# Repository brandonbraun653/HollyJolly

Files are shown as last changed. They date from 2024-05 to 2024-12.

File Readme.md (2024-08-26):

# First Clone
Initialize the Pico-SDK by running the following commands:
```bash
git submodule init
cd lib/pico-sdk
git submodule init
```

# Install the OpenOCD Debugger
The latest version of OpenOCD includes support for the RPI pico. Follow the
instructions here to compile and install from source:
https://github.com/openocd-org/openocd

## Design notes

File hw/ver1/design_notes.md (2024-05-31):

- From initial testing, the WS2812 needs to have the data line level shifted up to 5v. I got lucky in that my
chips in my neopixel string accepted the 3.3v logic level of the RP2040.

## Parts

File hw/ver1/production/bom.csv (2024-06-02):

Designator | Footprint | Quantity | Value | LCSC Part #
C1, C13, C14, C17, C18, C19, C20, C21, C22, C23, C24, C25, C26, C27, C28, C29, C3, C30, C31, C32, C33, C34, C35, C36, C37, C38, C39, C4, C40, C41, C42, C43, C44, C45, C46, C47, C48, C49, C5, C50, C6, C7, C8, C9 | 0402 | 44 | 100nF | C1525
C10, C11, C12, C2 | 0402 | 4 | 4.7uF | C23733
C15, C16 | 0402 | 2 | 10pF | C32949
D1, D10, D11, D12, D13, D14, D15, D16, D17, D18, D19, D2, D20, D21, D22, D23, D24, D25, D26, D27, D28, D29, D3, D30, D31, D32, D4, D5, D6, D7, D8, D9 | LED_WS2812B-2020_PLCC4_2.0x2.0mm | 32 | WS2812B-2020 | C5349955
J1 | MicroXNJ073 | 1 | USB_B_Micro | C404969
Q1 | SOT-23 | 1 | 2N7002 | C8545
R1, R2, R5, R6, R7, R8 | 0402 | 6 | 10k | C25744
R3, R4 | 0402 | 2 | 22 | C25092
SW1 | SW_Push_SPST_NO_Alps_SKRK | 1 | BOOT | C262416
SW2 | SW_Push_SPST_NO_Alps_SKRK | 1 | CYCLE | C262416
SW3 | SW_Push_SPST_NO_Alps_SKRK | 1 | BRIGHT | C262416
TP1 | TestPoint_Pad_1.0x1.0mm | 1 | SWD_CLK
TP2 | TestPoint_Pad_1.0x1.0mm | 1 | SWD_DATA
TP3 | TestPoint_Pad_1.0x1.0mm | 1 | LED_DATA_TP
U1 | QFN-56-1EP_7x7mm_P0.4mm_EP3.2x3.2mm | 1 | RP2040 | C2040
U2 | SOIC-8_5.23x5.23mm_P1.27mm | 1 | W25Q128JVS | C97521
U3 | SOT-23-3 | 1 | XC6206PxxxMR | C5446
Y1 | Crystal_SMD_3225-4Pin_3.2x2.5mm | 1 | 12MHz | C9002

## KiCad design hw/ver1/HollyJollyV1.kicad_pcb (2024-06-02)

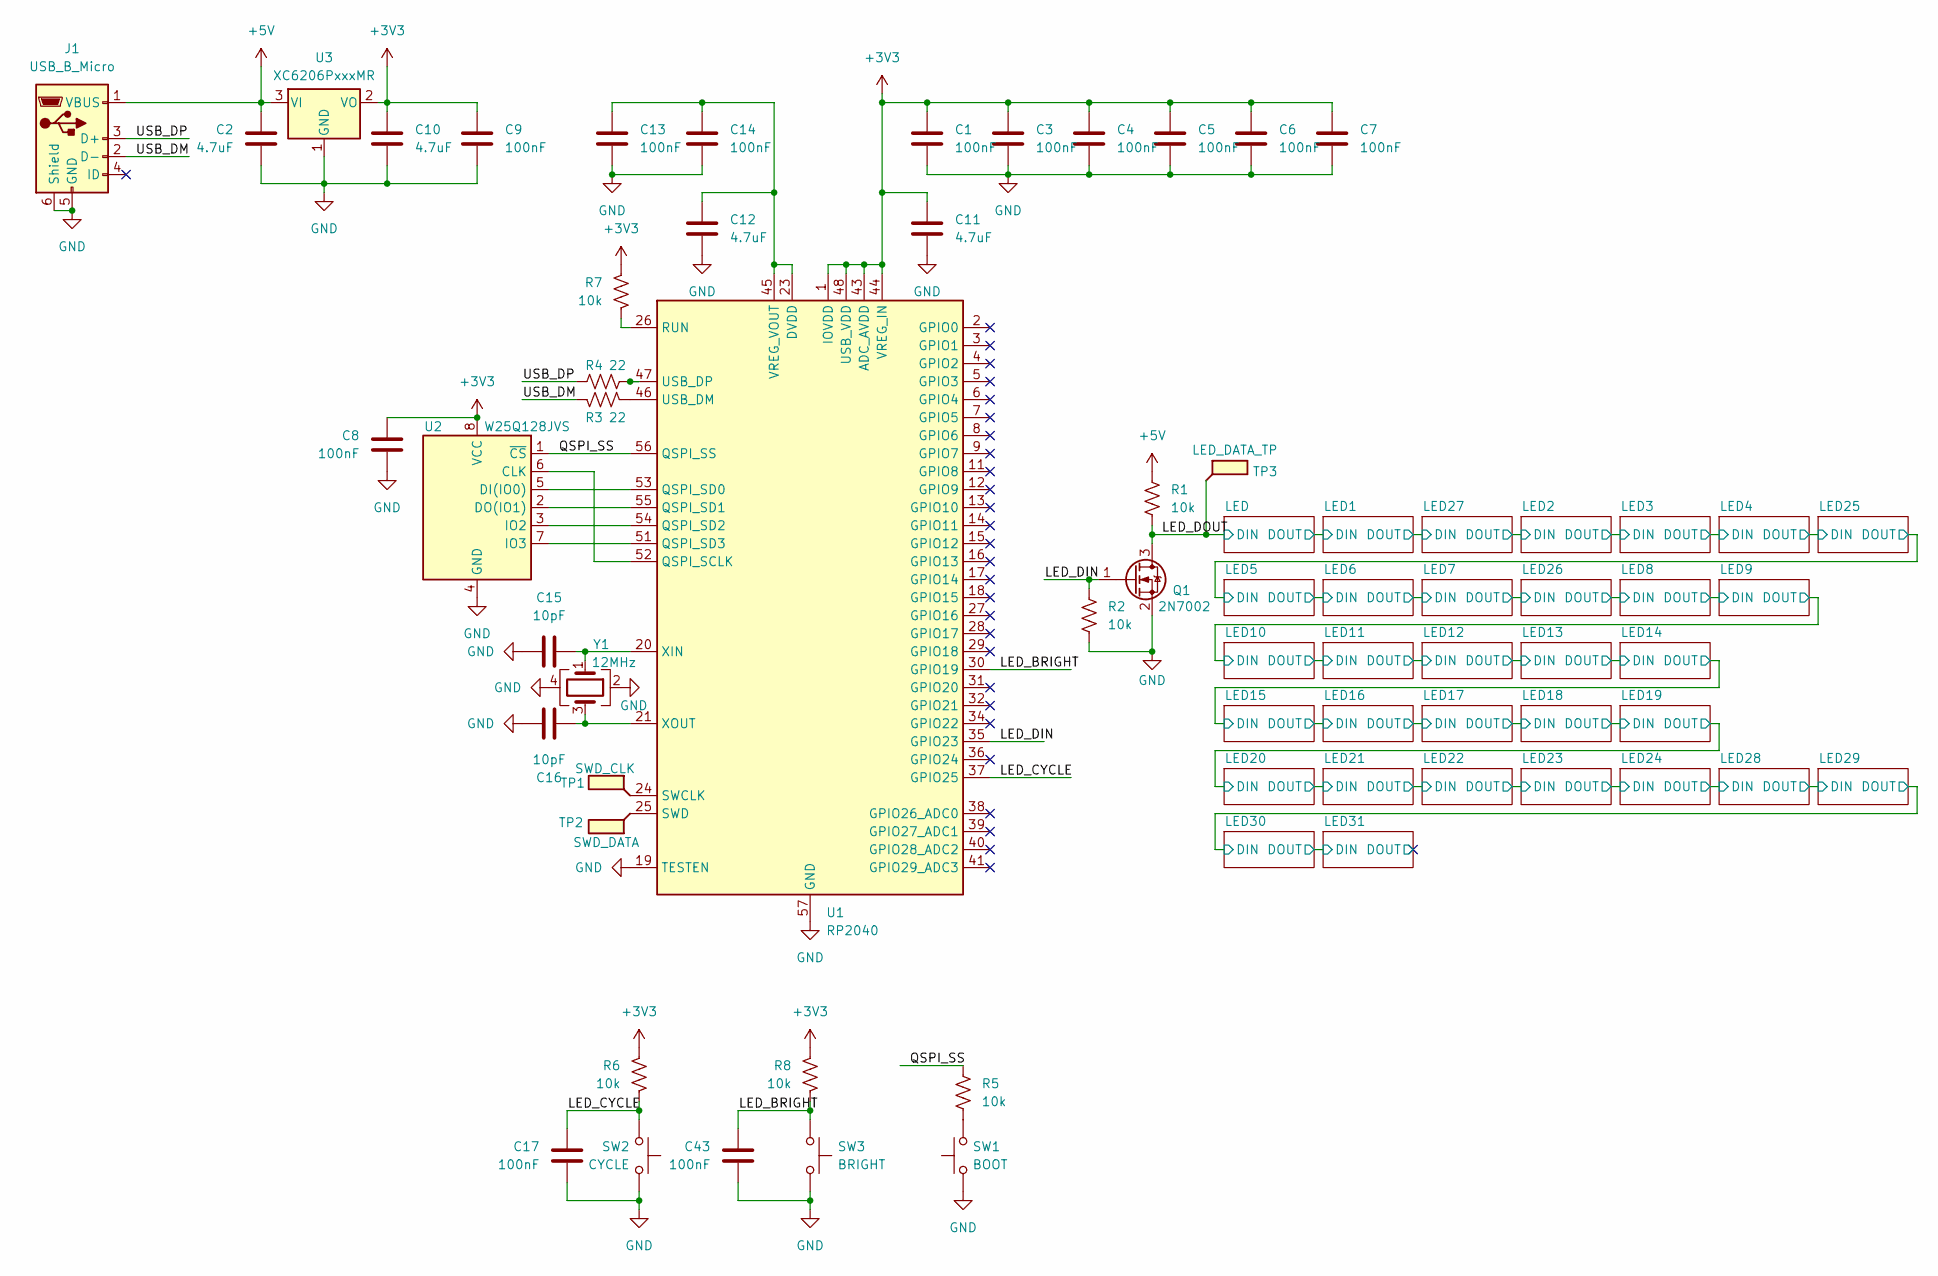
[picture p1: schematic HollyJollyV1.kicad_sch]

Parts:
C1, C3, C4, C5, C6, C7, C8, C9, C13, C14, C17, C43: 100nF; C_0402_1005Metric; MPN CL05B104KO5NNNC; LCSC C1525
C2, C10, C11, C12: 4.7uF; C_0402_1005Metric; MPN CL05A475MP5NRNC; LCSC C23733
C15, C16: 10pF; C_0402_1005Metric; MPN CL05C100JB5NNNC; LCSC C32949
J1: USB_B_Micro; MicroXNJ073; MPN MicroXNJ073; LCSC C404969
Q1: 2N7002; SOT-23; MPN 2N7002; LCSC C8545
R1, R2, R5, R6, R7, R8: 10k; R_0402_1005Metric; MPN 0402WGF1002TCE; LCSC C25744
R3, R4: 22; R_0402_1005Metric; MPN 0402WGF220JTCE; LCSC C25092
SW1: BOOT; SW_Push_SPST_NO_Alps_SKRK; MPN SKRKAGE020; LCSC C262416
SW2: CYCLE; SW_Push_SPST_NO_Alps_SKRK; MPN SKRKAGE020; LCSC C262416
SW3: BRIGHT; SW_Push_SPST_NO_Alps_SKRK; MPN SKRKAGE020; LCSC C262416
TP1: SWD_CLK; TestPoint_Pad_1.0x1.0mm
TP2: SWD_DATA; TestPoint_Pad_1.0x1.0mm
TP3: LED_DATA_TP; TestPoint_Pad_1.0x1.0mm
U1: RP2040; QFN-56-1EP_7x7mm_P0.4mm_EP3.2x3.2mm; MPN RP2040; LCSC C2040
U2: W25Q128JVS; SOIC-8_5.23x5.23mm_P1.27mm; MPN W25Q128JVSIQ; LCSC C97521
U3: XC6206PxxxMR; SOT-23-3; MPN XC6206P332MR-G; LCSC C5446
Y1: 12MHz; Crystal_SMD_3225-4Pin_3.2x2.5mm; MPN X322512MSB4SI; LCSC C9002

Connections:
+3V3: C1.1, C3.1, C4.1, C5.1, C6.1, C7.1, C8.1, C9.1, C10.1, C11.1, R6.2, R7.1, R8.2, U1.1 (IOVDD), U1.10 (IOVDD), U1.22 (IOVDD), U1.33 (IOVDD), U1.42 (IOVDD), U1.43 (ADC_AVDD), U1.44 (VREG_IN), U1.48 (USB_VDD), U1.49 (IOVDD), U2.8 (VCC), U3.2 (VO)
+5V: C2.1, J1.1 (VBUS), R1.1, U3.3 (VI); also elsewhere on the board
/LED_BRIGHT: C43.1, R8.1, SW3.2, U1.30 (GPIO19)
/LED_CYCLE: C17.1, R6.1, SW2.2, U1.37 (GPIO25)
/LED_DIN: Q1.1 (G), R2.1, U1.35 (GPIO23)
/LED_DOUT: Q1.3 (D), R1.2, TP3.1; also elsewhere on the board
/QSPI_SS: R5.1, U1.56 (QSPI_SS), U2.1 (~CS)
/USB_DM: J1.2 (D-), R3.1
/USB_DP: J1.3 (D+), R4.1
GND: C1.2, C2.2, C3.2, C4.2, C5.2, C6.2, C7.2, C8.2, C9.2, C10.2, C11.2, C12.2, C13.2, C14.2, C15.1, C16.1, C17.2, C43.2, J1.5 (GND), J1.6 (Shield), Q1.2 (S), R2.2, SW1.1, SW2.1, SW3.1, U1.19 (TESTEN), U1.57 (GND), U2.4 (GND), U3.1 (GND), Y1.2, Y1.4; also elsewhere on the board
unnamed: R5.2, SW1.2
unnamed: U1.52 (QSPI_SCLK), U2.6 (CLK)
unnamed: U1.53 (QSPI_SD0), U2.5 (DI(IO0))
unnamed: U1.55 (QSPI_SD1), U2.2 (DO(IO1))
unnamed: U1.54 (QSPI_SD2), U2.3 (IO2)
unnamed: U1.51 (QSPI_SD3), U2.7 (IO3)
unnamed: R7.2, U1.26 (RUN)
unnamed: TP1.1, U1.24 (SWCLK)
unnamed: TP2.1, U1.25 (SWD)
unnamed: R3.2, U1.46 (USB_DM)
unnamed: R4.2, U1.47 (USB_DP)
unnamed: C12.1, C13.1, C14.1, U1.23 (DVDD), U1.45 (VREG_VOUT), U1.50 (DVDD)
unnamed: C15.2, U1.20 (XIN), Y1.1
unnamed: C16.2, U1.21 (XOUT), Y1.3

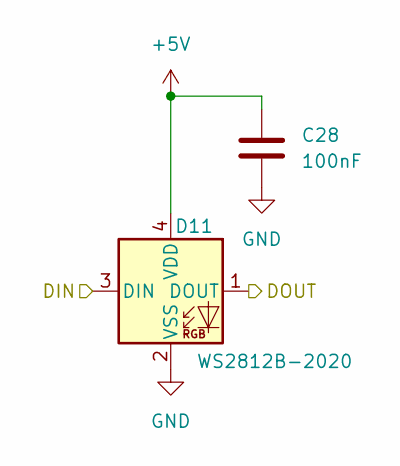
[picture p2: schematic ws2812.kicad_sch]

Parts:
C28: 100nF; C_0402_1005Metric; MPN CL05B104KO5NNNC; LCSC C1525
D11: WS2812B-2020; LED_WS2812B-2020_PLCC4_2.0x2.0mm; MPN XL-2020RGBC-WS2812B; LCSC C5349955

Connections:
+5V: C28.1, D11.4 (VDD); also elsewhere on the board
/LED10/DIN: D11.3 (DIN); also elsewhere on the board
/LED10/DOUT: D11.1 (DOUT); also elsewhere on the board
GND: C28.2, D11.2 (VSS); also elsewhere on the board

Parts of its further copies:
C18, C19, C20, C21, C22, C23, C24, C25, C26, C27, C29, C30, C31, C32, C33, C34, C35, C36, C37, C38, C39, C40, C41, C42, C44, C45, C46, C47, C48, C49, C50: 100nF; C_0402_1005Metric; MPN CL05B104KO5NNNC; LCSC C1525
D1, D2, D3, D4, D5, D6, D7, D8, D9, D10, D12, D13, D14, D15, D16, D17, D18, D19, D20, D21, D22, D23, D24, D25, D26, D27, D28, D29, D30, D31, D32: WS2812B-2020; LED_WS2812B-2020_PLCC4_2.0x2.0mm; MPN XL-2020RGBC-WS2812B; LCSC C5349955

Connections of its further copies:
+5V: C18.1, C19.1, C20.1, C21.1, C22.1, C23.1, C24.1, C25.1, C26.1, C27.1, C29.1, C30.1, C31.1, C32.1, C33.1, C34.1, C35.1, C36.1, C37.1, C38.1, C39.1, C40.1, C41.1, C42.1, C44.1, C45.1, C46.1, C47.1, C48.1, C49.1, C50.1, D1.4 (VDD), D2.4 (VDD), D3.4 (VDD), D4.4 (VDD), D5.4 (VDD), D6.4 (VDD), D7.4 (VDD), D8.4 (VDD), D9.4 (VDD), D10.4 (VDD), D12.4 (VDD), D13.4 (VDD), D14.4 (VDD), D15.4 (VDD), D16.4 (VDD), D17.4 (VDD), D18.4 (VDD), D19.4 (VDD), D20.4 (VDD), D21.4 (VDD), D22.4 (VDD), D23.4 (VDD), D24.4 (VDD), D25.4 (VDD), D26.4 (VDD), D27.4 (VDD), D28.4 (VDD), D29.4 (VDD), D30.4 (VDD), D31.4 (VDD), D32.4 (VDD); also elsewhere on the board
/LED1/DOUT: D2.1 (DOUT), D28.3 (DIN)
/LED2/DIN: D3.3 (DIN), D28.1 (DOUT)
/LED2/DOUT: D3.1 (DOUT), D4.3 (DIN)
/LED3/DOUT: D4.1 (DOUT), D5.3 (DIN)
/LED5/DOUT: D6.1 (DOUT), D7.3 (DIN)
/LED6/DOUT: D7.1 (DOUT), D8.3 (DIN)
/LED8/DOUT: D9.1 (DOUT), D10.3 (DIN)
/LED10/DIN: D10.1 (DOUT); also elsewhere on the board
/LED10/DOUT: D12.3 (DIN); also elsewhere on the board
/LED11/DOUT: D12.1 (DOUT), D13.3 (DIN)
/LED12/DOUT: D13.1 (DOUT), D14.3 (DIN)
/LED13/DOUT: D14.1 (DOUT), D15.3 (DIN)
/LED14/DOUT: D15.1 (DOUT), D16.3 (DIN)
/LED15/DOUT: D16.1 (DOUT), D17.3 (DIN)
/LED16/DOUT: D17.1 (DOUT), D18.3 (DIN)
/LED17/DOUT: D18.1 (DOUT), D19.3 (DIN)
/LED18/DOUT: D19.1 (DOUT), D20.3 (DIN)
/LED19/DOUT: D20.1 (DOUT), D21.3 (DIN)
/LED20/DOUT: D21.1 (DOUT), D22.3 (DIN)
/LED21/DOUT: D22.1 (DOUT), D23.3 (DIN)
/LED22/DOUT: D23.1 (DOUT), D24.3 (DIN)
/LED23/DOUT: D24.1 (DOUT), D25.3 (DIN)
/LED24/DOUT: D25.1 (DOUT), D29.3 (DIN)
/LED25/DIN: D5.1 (DOUT), D26.3 (DIN)
/LED25/DOUT: D6.3 (DIN), D26.1 (DOUT)
/LED26/DIN: D8.1 (DOUT), D27.3 (DIN)
/LED26/DOUT: D9.3 (DIN), D27.1 (DOUT)
/LED28/DOUT: D29.1 (DOUT), D30.3 (DIN)
/LED29/DOUT: D30.1 (DOUT), D31.3 (DIN)
/LED30/DOUT: D31.1 (DOUT), D32.3 (DIN)
/LED31/DOUT: D32.1 (DOUT)
/LED/DOUT: D1.1 (DOUT), D2.3 (DIN)
/LED_DOUT: D1.3 (DIN); also elsewhere on the board
GND: C18.2, C19.2, C20.2, C21.2, C22.2, C23.2, C24.2, C25.2, C26.2, C27.2, C29.2, C30.2, C31.2, C32.2, C33.2, C34.2, C35.2, C36.2, C37.2, C38.2, C39.2, C40.2, C41.2, C42.2, C44.2, C45.2, C46.2, C47.2, C48.2, C49.2, C50.2, D1.2 (VSS), D2.2 (VSS), D3.2 (VSS), D4.2 (VSS), D5.2 (VSS), D6.2 (VSS), D7.2 (VSS), D8.2 (VSS), D9.2 (VSS), D10.2 (VSS), D12.2 (VSS), D13.2 (VSS), D14.2 (VSS), D15.2 (VSS), D16.2 (VSS), D17.2 (VSS), D18.2 (VSS), D19.2 (VSS), D20.2 (VSS), D21.2 (VSS), D22.2 (VSS), D23.2 (VSS), D24.2 (VSS), D25.2 (VSS), D26.2 (VSS), D27.2 (VSS), D28.2 (VSS), D29.2 (VSS), D30.2 (VSS), D31.2 (VSS), D32.2 (VSS); also elsewhere on the board

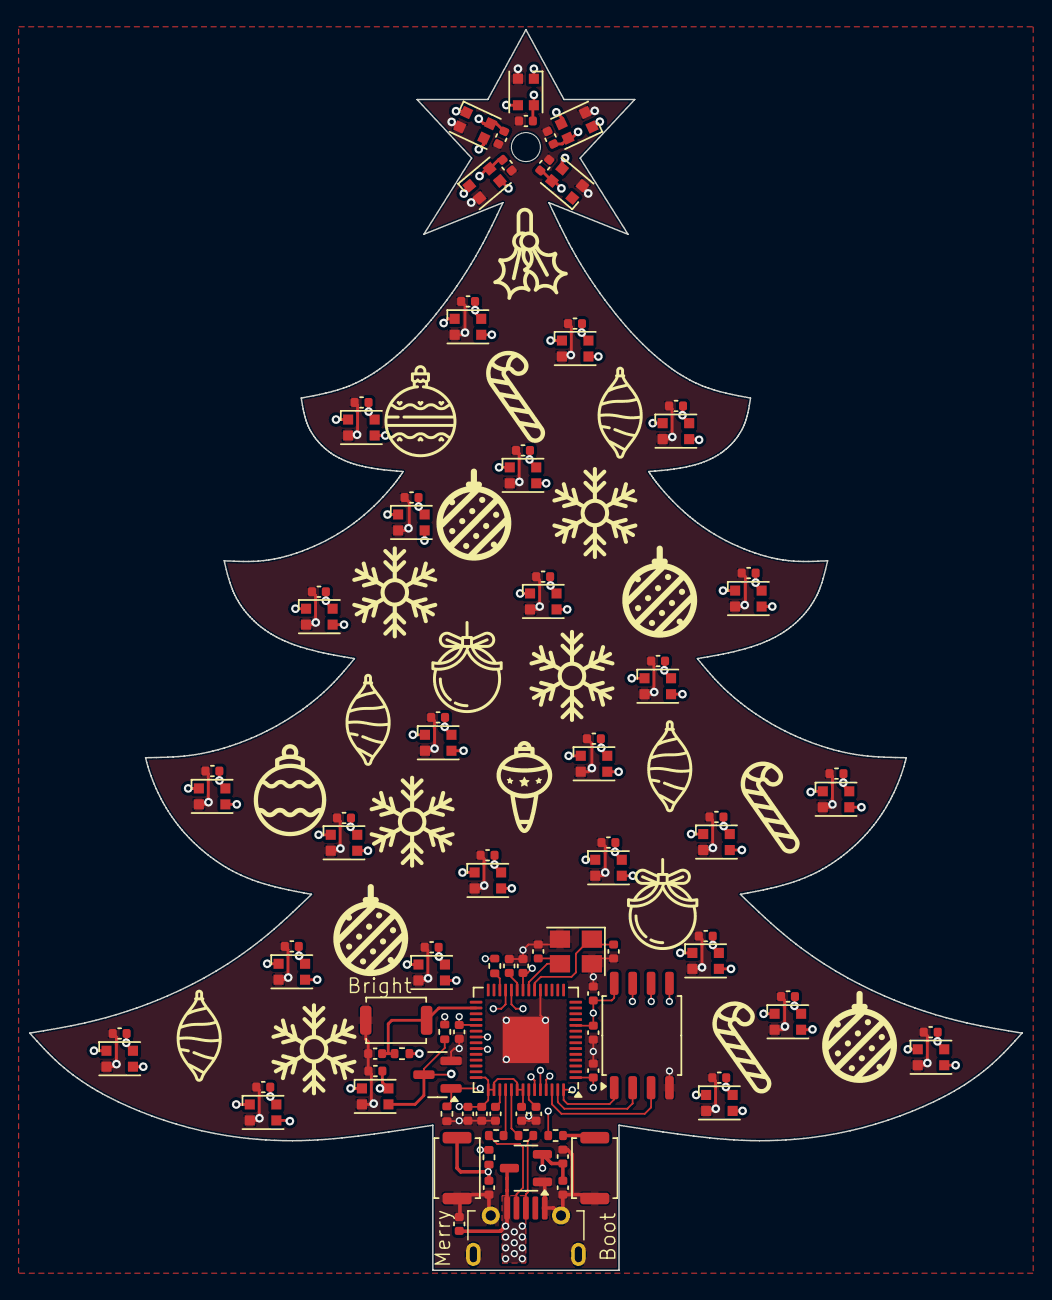
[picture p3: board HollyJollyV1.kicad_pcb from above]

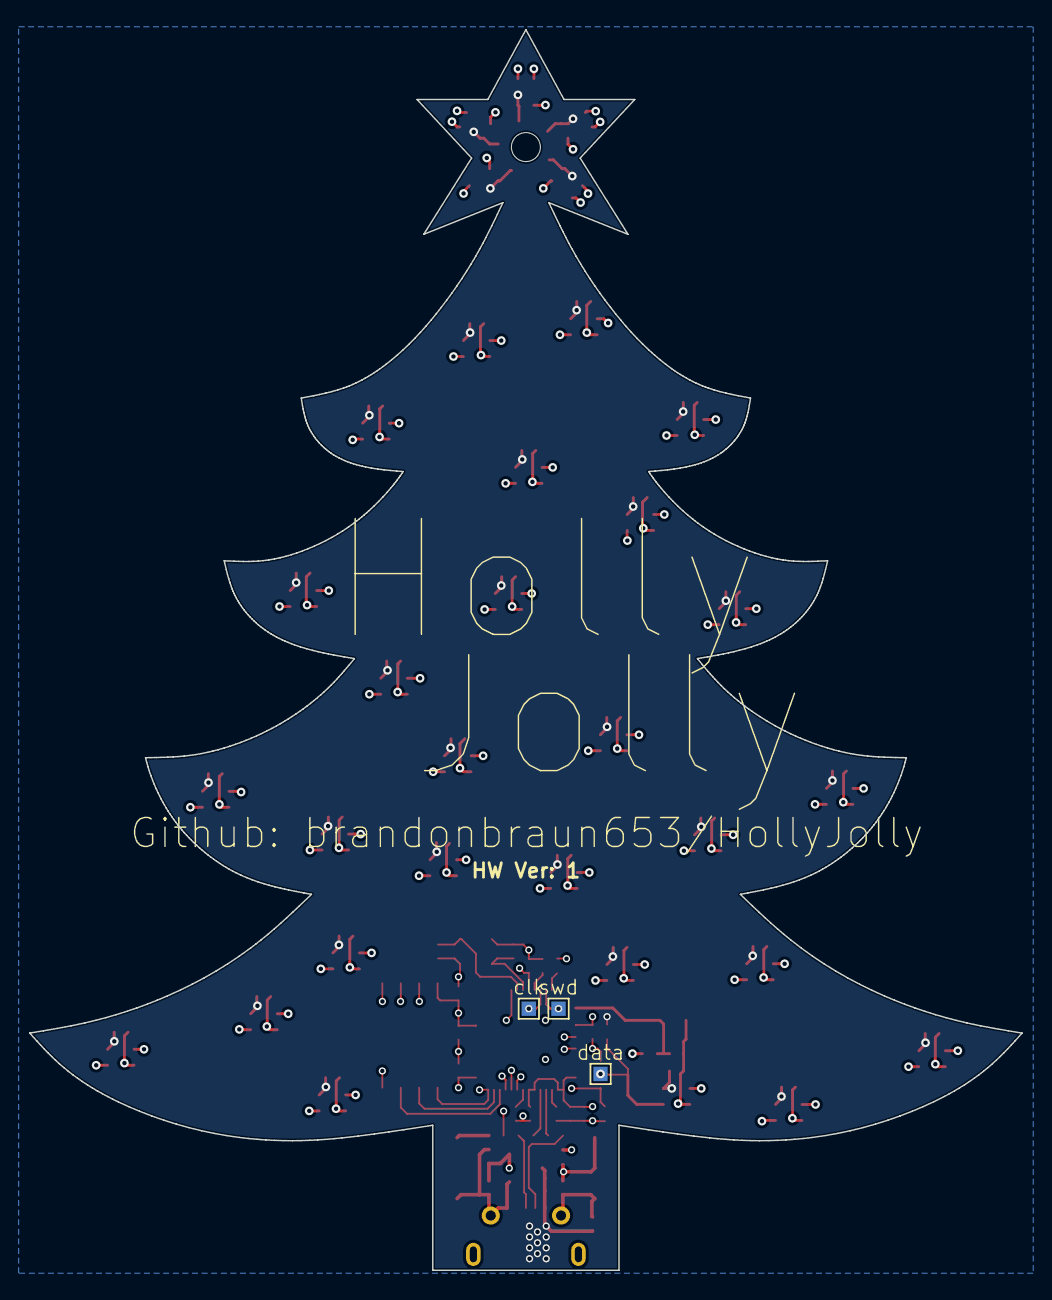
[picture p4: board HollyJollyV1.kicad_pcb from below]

Board: 4 copper layers, 68.5 x 85.6 mm, 102 parts (3 on the bottom side), 55 nets.

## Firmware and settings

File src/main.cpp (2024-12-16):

#include "animator.hpp"
#include "buttons.hpp"
#include "holly_jolly_cfg.hpp"
#include "pico/multicore.h"
#include "pico_debug.h"
#include "ws2812.hpp"
#include <cstring>


static void core0_entry()
{
  /*---------------------------------------------------------------------------
  Initialize hardware resources and the animator subsystem
  ---------------------------------------------------------------------------*/
  LED::initialize();
  Buttons::initialize();
  Animator::initialize();

  while( 1 )
  {
    sleep_ms( FRAME_REFRESH_RATE_MS );
    Buttons::process();
    Animator::process();
  }
}


static void core1_entry()
{
  /*---------------------------------------------------------------------------
  Initialize the USB port
  ---------------------------------------------------------------------------*/
  pico_debug_init();

  /*---------------------------------------------------------------------------
  Start the main loop
  ---------------------------------------------------------------------------*/
  pico_debug_core_x_thread();
}


int main()
{
  /*---------------------------------------------------------------------------
  Initialize system resources
  ---------------------------------------------------------------------------*/
  timer_hw->dbgpause = 0;    // Do not pause the timer during debug
  pico_debug_configure_clocks();

  /*---------------------------------------------------------------------------
  Start the secondary core
  ---------------------------------------------------------------------------*/
  multicore_launch_core1( core1_entry );

  /*---------------------------------------------------------------------------
  Main loop
  ---------------------------------------------------------------------------*/
  sleep_ms( 1000 );
  core0_entry();

  return 0;
}

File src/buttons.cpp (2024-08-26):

/******************************************************************************
 *  File Name:
 *    buttons.cpp
 *
 *  Description:
 *    Driver implementation for the physical buttons on the Holly Jolly
 *
 *  2024 | Brandon Braun | brandonbraun653@protonmail.com
 *****************************************************************************/

/*-----------------------------------------------------------------------------
Includes
-----------------------------------------------------------------------------*/
#include "buttons.hpp"
#include "hardware/gpio.h"
#include "pico/time.h"
#include "pico/types.h"
#include <cstdint>

namespace Buttons
{
  /*---------------------------------------------------------------------------
  Constants
  ---------------------------------------------------------------------------*/

  static constexpr uint     s_pin_input_bright = 19;
  static constexpr uint     s_pin_input_action = 25;
  static constexpr uint32_t s_debounce_ms      = 50;

  /*---------------------------------------------------------------------------
  Static Variables
  ---------------------------------------------------------------------------*/

  static volatile ButtonCallback s_bright_press_cb;
  static volatile ButtonCallback s_action_press_cb;
  static volatile uint32_t       s_last_bright_press_time;
  static volatile uint32_t       s_last_action_press_time;
  static volatile bool           s_pending_bright_press;
  static volatile bool           s_pending_action_press;

  /*---------------------------------------------------------------------------
  Static Function Definitions
  ---------------------------------------------------------------------------*/

  /**
   * @brief IRQ handler to process button press events
   *
   * @param gpio  The GPIO pin that triggered the event
   * @param event_mask  The type of event that occurred
   */
  static void irqh_button_press( uint gpio, uint32_t event_mask )
  {
    /*-------------------------------------------------------------------------
    Only process falling edge events. Per the hardware schematic, the buttons
    are active low.
    -------------------------------------------------------------------------*/
    if( ( event_mask & GPIO_IRQ_EDGE_FALL ) != GPIO_IRQ_EDGE_FALL )
    {
      return;
    }

    /*-------------------------------------------------------------------------
    Determine which button was pressed and record the time. Actual processing
    will occur in the main loop.
    -------------------------------------------------------------------------*/
    if( ( gpio == s_pin_input_bright ) && !s_pending_bright_press )
    {
      s_pending_bright_press   = true;
      s_last_bright_press_time = to_ms_since_boot( get_absolute_time() );
    }
    else if( ( gpio == s_pin_input_action ) && !s_pending_action_press )
    {
      s_pending_action_press   = true;
      s_last_action_press_time = to_ms_since_boot( get_absolute_time() );
    }
  }

  /*---------------------------------------------------------------------------
  Public Functions
  ---------------------------------------------------------------------------*/

  void initialize()
  {
    /*-------------------------------------------------------------------------
    Initialize the static variables
    -------------------------------------------------------------------------*/
    s_bright_press_cb        = nullptr;
    s_action_press_cb        = nullptr;
    s_last_bright_press_time = 0;
    s_last_action_press_time = 0;
    s_pending_bright_press   = false;
    s_pending_action_press   = false;

    /*-------------------------------------------------------------------------
    Initialize the GPIO pins for button inputs
    -------------------------------------------------------------------------*/
    gpio_init( s_pin_input_bright );
    gpio_set_dir( s_pin_input_bright, GPIO_IN );
    gpio_pull_up( s_pin_input_bright );
    gpio_set_irq_enabled_with_callback( s_pin_input_bright, GPIO_IRQ_EDGE_FALL, true, irqh_button_press );

    gpio_init( s_pin_input_action );
    gpio_set_dir( s_pin_input_action, GPIO_IN );
    gpio_pull_up( s_pin_input_action );
    gpio_set_irq_enabled_with_callback( s_pin_input_action, GPIO_IRQ_EDGE_FALL, true, irqh_button_press );
  }


  void process()
  {
    const uint32_t current_time = to_ms_since_boot( get_absolute_time() );

    /*-------------------------------------------------------------------------
    Process the brightness control input
    -------------------------------------------------------------------------*/
    if( s_pending_bright_press && ( ( current_time - s_last_bright_press_time ) >= s_debounce_ms ) )
    {
      if( s_bright_press_cb && ( gpio_get( s_pin_input_bright ) == 0 ) )
      {
        s_bright_press_cb();
      }

      s_pending_bright_press = false;
    }

    /*-------------------------------------------------------------------------
    Process the action control input
    -------------------------------------------------------------------------*/
    if( s_pending_action_press && ( ( current_time - s_last_action_press_time ) >= s_debounce_ms ) )
    {
      if( s_action_press_cb && ( gpio_get( s_pin_input_action ) == 0 ) )
      {
        s_action_press_cb();
      }

      s_pending_action_press = false;
    }
  }


  void onBrightKeyPress( ButtonCallback callback )
  {
    s_bright_press_cb = callback;
  }


  void onActionKeyPress( ButtonCallback callback )
  {
    s_action_press_cb = callback;
  }

}    // namespace Buttons

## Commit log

2024-05-08 Add the pico-sdk and get the blinky example building/running
2024-05-11 Get the debug interface working with second pico
2024-05-31 Get a very simple neopixel strip to light up on the pico development board
2024-06-02 Add hardware version 1 design files
    [HollyJollyV1.kicad_pcb, HollyJollyV1.kicad_sch, bom.csv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]
2024-08-26 Version one driver initialized. Added a few animations.
2024-12-16 Pull up kicadlib
2024-12-16 Add initial driver set
